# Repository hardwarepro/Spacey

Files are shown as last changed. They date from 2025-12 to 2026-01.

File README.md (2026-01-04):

# Spacey
A fully open-source space mouse! The current space mouse costs around $350 USD, so being able to build it for ~$75 USD is a HUGE reduction is cost for the same features (minus the screen). It has 10 hotkeyabled buttons, LEDs, a magnetometor for the space mouse part of it, and an amazingly designed CAD!

There are 2 main parts to this space mouse, the CAD + PCB for the keyboard, and the few parts for the space mouse part of it. Some photos of the CAD can be seen below, and can be viewed [here](https://cad.onshape.com/documents/f05fe75dfc18f89f5fcec945/w/6a3c1056693be4c34d9f2601/e/94b3cceea32ed90fe954c1a2). The PCB controls all the hotkeys, and the Xiao + magnetometor controls the actual space mouse ascpect. The space mouse part was partially taken from a tutorial though this was fully expanded to support hotkeys to act like the real and production-wise space mouse. Since the tutorial only convered those few main parts, all of the PCB + CAD shown below was all designed by myself.

## Photos

Screenshot 2025-12-13 at 5 34 07 PM

Screenshot 2025-12-13 at 5 34 35 PM



Screenshot 2025-12-12 at 12 20 18 AM

Screenshot 2025-12-12 at 12 20 33 AM

## BOM

## Full Total: $77.47 USD

## Parts for the Keyboard Part of it
| Item | Description | Quantity | Unit Price ($) | Total Price ($) | URL | Running Total ($ with Tax) |
|---|---|---|---|---|---|---|
| PCB | My PCB | x5 | $23.08 | $3.08 | [Link](https://jlcpcb.com) | $3.08 |
| Case | 3D Printed | 1 | Free | Free | N/A | $0 |
| XIAO-nRF52840 | MCU | 1 | $11.63 | $19.62 | [Link](https://ca.robotshop.com/fr/products/seeedstudioxiaonrf52840-fr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) | $19.62 |
| Buttons + LEDs + Screw Terminal | LCSC Parts for the PCB | 15 | $20 | $20 | [Link](https://lcsc.com) | $20 |
## Total with shipping + tax (USD): $42.7

## Parts for the space mouse part of it
| Item | Description | Quantity | Unit Price ($) | Total Price ($) | URL | Running Total ($ with Tax) |
|---|---|---|---|---|---|---|
| Adafruit QT Py RP2040 | MCU | 1 | $9.95 | $9.95 | [Link](https://www.adafruit.com/product/4900) | N/A |
| STEMMA QT / Qwiic JST SH 4-pin Cable - 50mm Long | JST Cable | 1 | $0.95 | $0.95 | [Link][https://www.adafruit.com/product/4210](https://www.aliexpress.com/item/1005007590874378.html) | N/A |
| Adafruit TLV493D | The main chip for the mouse- the magnetometer | 1 | $5.71 | $7.70 | [Link][https://www.aliexpress.com/item/1005007590874378.html](https://www.adafruit.com/product/4366) | N/A |
| Magnets | For the magnetometer | 1 | Free | Free | N/A | N/A |
## Total with shipping + tax (USD): $34.77

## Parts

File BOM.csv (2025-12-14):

Full Total | $77.47 USD
Parts for the Keyboard Part of it
Item | Description | Quantity | Unit Price ($) | Total Price ($) | URL | Running Total ($ with Tax)
PCB | My PCB | x5 | $23.08 | $3.08 | https://jlcpcb.com | $3.08
Case | 3D Printed | 1 | Free | Free | N/A | $0.00
XIAO-nRF52840 | MCU | 1 | $11.63 | $19.62 | https://ca.robotshop.com/fr/products/seeedstudioxiaonrf52840-fr | $19.62
Buttons + LEDs + Screw Terminal | LCSC Parts for the PCB | 15 | $20.00 | $20.00 | https://lcsc.com | $20.00
Total with shipping + tax (USD) | $42.70
Parts for the space mouse part of it
Item | Description | Quantity | Unit Price ($) | Total Price ($) | URL | Running Total ($ with Tax)
Adafruit QT Py RP2040 | MCU | 1 | $9.95 | $9.95 | https://www.adafruit.com/product/4900 | N/A
STEMMA QT / Qwiic JST SH 4-pin Cable - 50mm Long | JST Cable | 1 | $0.95 | $0.95 | https://www.adafruit.com/product/4210 | N/A
Adafruit TLV493D | The main chip for the mouse- the magnetometer | 1 | $5.95 | $5.95 | https://www.adafruit.com/product/4366 | N/A
Magnets | For the magnetometer | 1 | Free | Free | N/A | N/A
Total with shipping + tax (USD) | $34.77

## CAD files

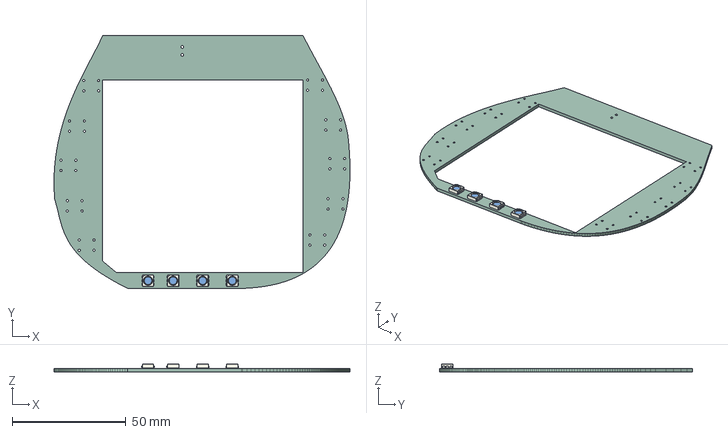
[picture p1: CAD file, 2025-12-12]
PCB/PCB.step
129.9 x 111.0 x 3.45 mm
LED_WS2812_PLCC6_5.0x5.0mm_P1.6mm x 4
spacey_PCB

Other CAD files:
PCB/.step

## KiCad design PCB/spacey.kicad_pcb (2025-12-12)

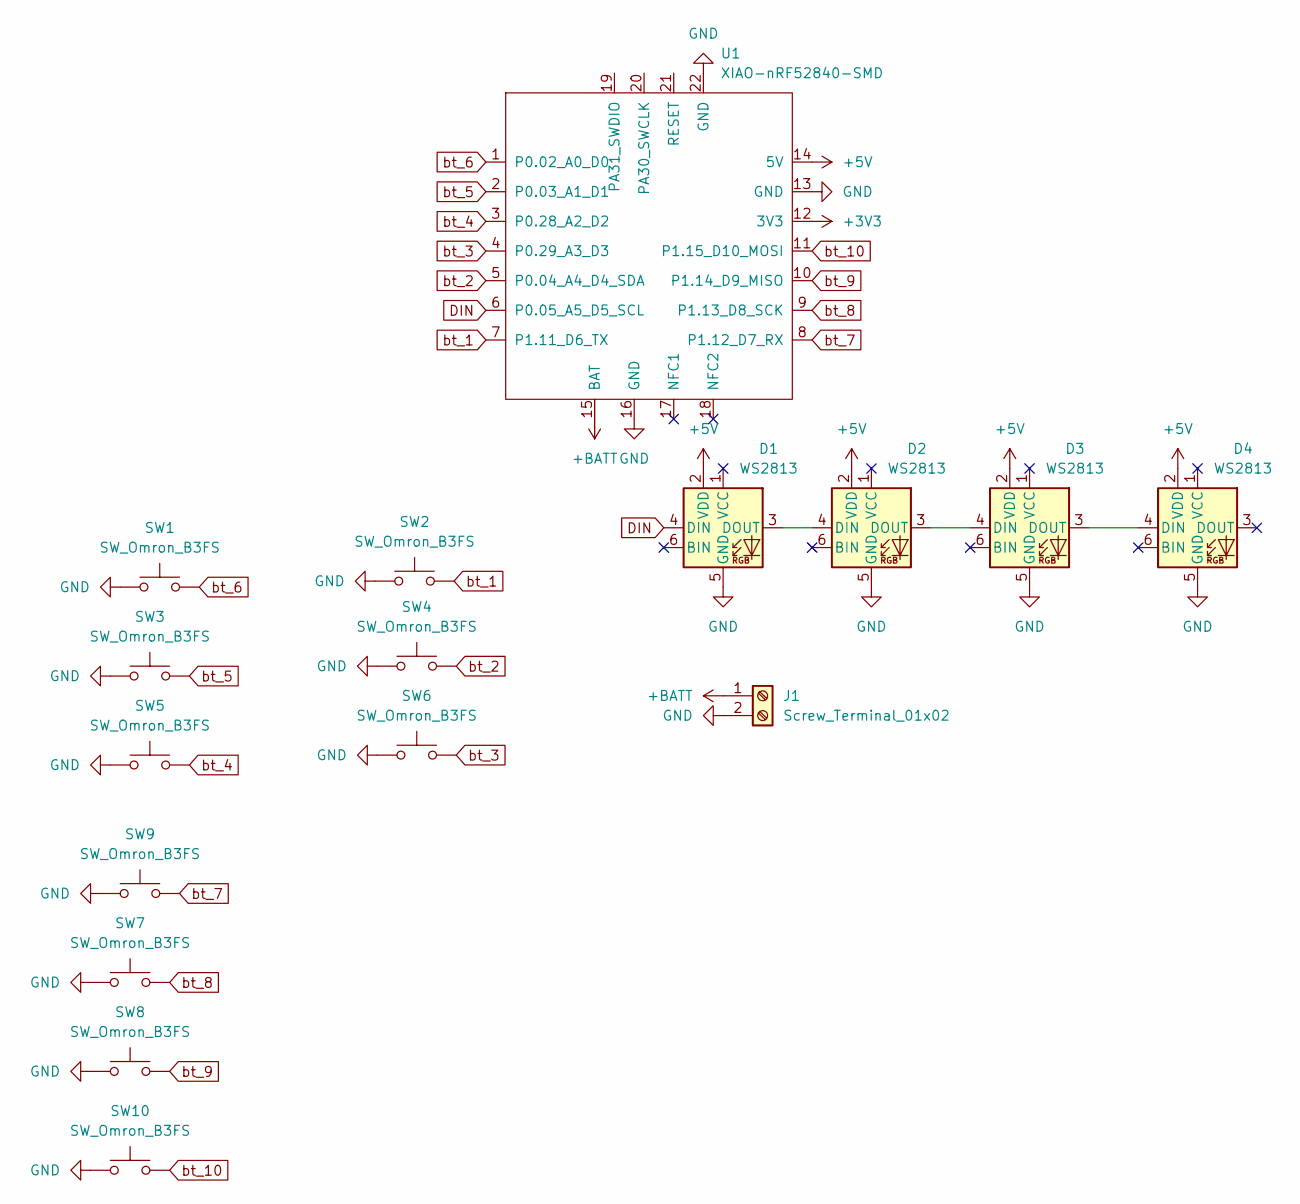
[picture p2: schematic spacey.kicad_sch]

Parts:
D1, D2, D3, D4: WS2813; LED_WS2812_PLCC6_5.0x5.0mm_P1.6mm
J1: Screw_Terminal_01x02; TerminalBlock_4Ucon_1x02_P3.50mm_Horizontal
SW1, SW2, SW3, SW4, SW5, SW6, SW7, SW8, SW9, SW10: SW_Omron_B3FS; SW_TH_Tactile_Omron_B3F-10xx
U1: XIAO-nRF52840-SMD

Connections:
+3V3: U1.12 (3V3)
+5V: D1.2 (VDD), D2.2 (VDD), D3.2 (VDD), D4.2 (VDD), U1.14 (5V)
+BATT: J1.1, U1.15 (BAT)
DIN: D1.4 (DIN), U1.6 (P0.05_A5_D5_SCL)
GND: D1.5 (GND), D2.5 (GND), D3.5 (GND), D4.5 (GND), J1.2, SW1.1, SW2.1, SW3.1, SW4.1, SW5.1, SW6.1, SW7.1, SW8.1, SW9.1, SW10.1, U1.13 (GND), U1.16 (GND), U1.22 (GND)
unnamed: D1.3 (DOUT), D2.4 (DIN)
unnamed: D2.3 (DOUT), D3.4 (DIN)
unnamed: D3.3 (DOUT), D4.4 (DIN)
bt_1: SW2.2, U1.7 (P1.11_D6_TX)
bt_2: SW4.2, U1.5 (P0.04_A4_D4_SDA)
bt_3: SW6.2, U1.4 (P0.29_A3_D3)
bt_4: SW5.2, U1.3 (P0.28_A2_D2)
bt_5: SW3.2, U1.2 (P0.03_A1_D1)
bt_6: SW1.2, U1.1 (P0.02_A0_D0)
bt_7: SW9.2, U1.8 (P1.12_D7_RX)
bt_8: SW7.2, U1.9 (P1.13_D8_SCK)
bt_9: SW8.2, U1.10 (P1.14_D9_MISO)
bt_10: SW10.2, U1.11 (P1.15_D10_MOSI)

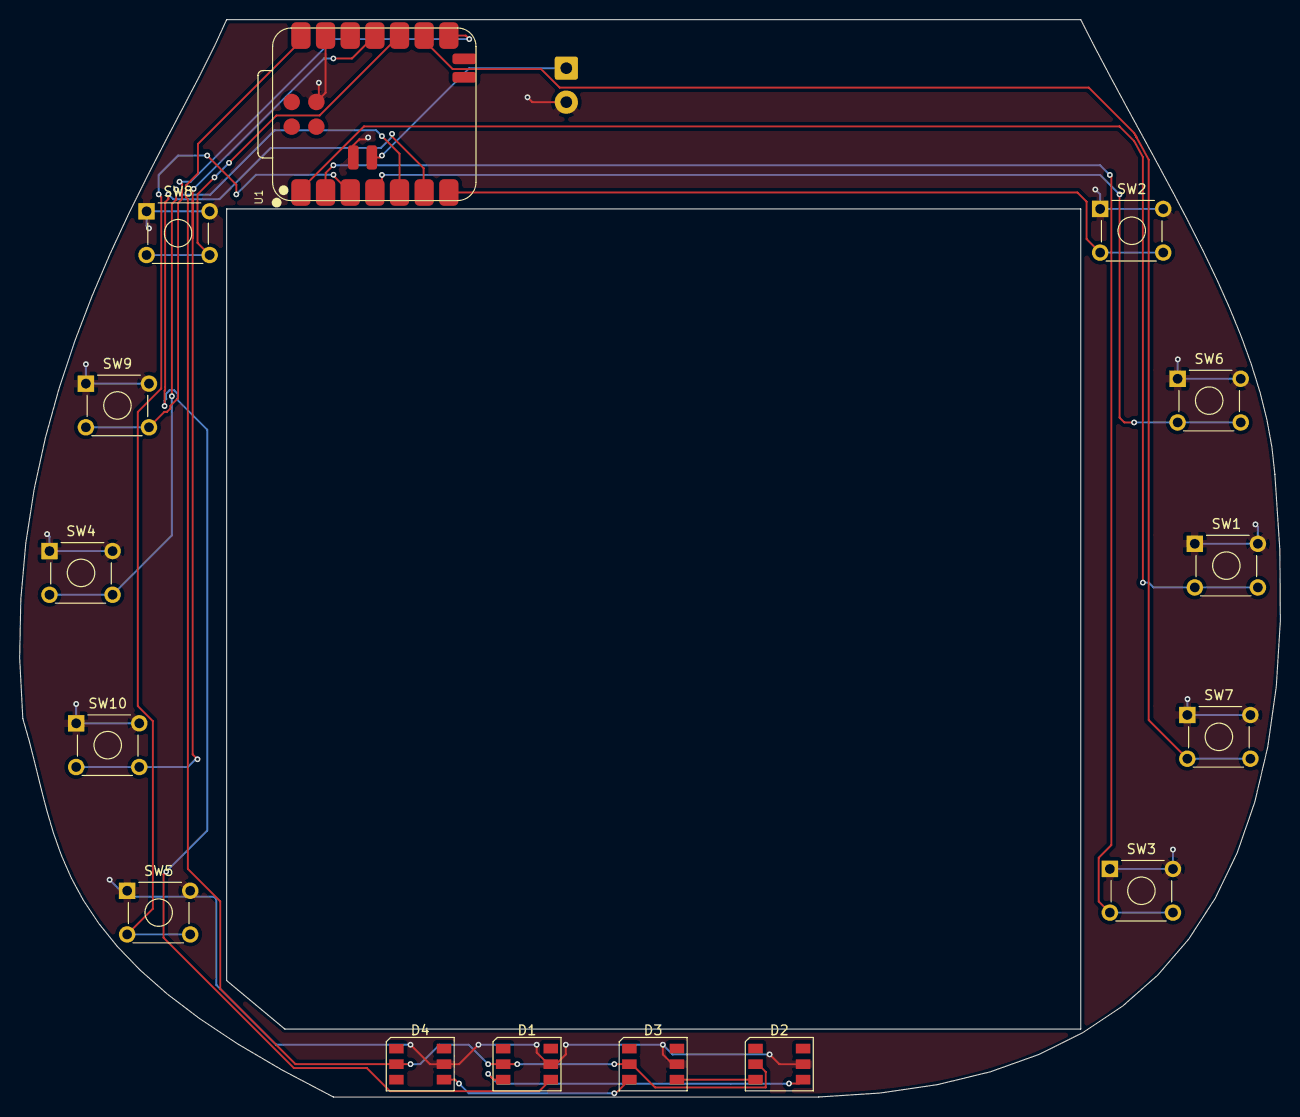
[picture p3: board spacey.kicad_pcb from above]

Board: 2 copper layers, 129.9 x 111.0 mm, 16 parts (1 on the bottom side), 17 nets.

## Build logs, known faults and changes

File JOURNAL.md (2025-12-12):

# Total time spent: 11 hours

## November 27th- 3 hours
### Schematic Making Time!
I was going through instrutables and I was looking for some cool projects related to CAD, as that is what I do a lot these days, and I stumbled across something called the Space Mouse. What this mouse does is it allows you to maintain greater control in your CAD space as there is usually a lot of buttons and stuff. This simplifies it to just a 3-axis wheel. After seeing this, I decided that I wanted to build it myself. The only problem I had was that if I only built the 3-axis wheel, I would mostly just be copying the tutorial and not actually making a PCB or anything. To combat this, I decided that I wanted to build the "more expensive space mouse" from scratch which also includes buttons for hotkeys, and a small screen for some quick actions. This will allow me to follow the tutorial on what parts to buy for the 3-axis part, while still allowing me to build the PCB for keyboard + screen aspect. On top of this, I hope to build all the CAD from scratch too and not using the tutorial's CAD for it. This is because I need it to be one piece for the keyboard + screen part too. So far, what I have done is build the schematic for the keys + a few LEDs to allow for some sick ambient lighting. I did a little bit of research and found that I wanted to use the bigger Xiao chip as it has more IO to allow me to add the right amount of keys + the LEDs + the screen. Even though this chip does have BL built it, it's not my goal to use it.


## December 11th- 4.5 hours
### Routed the PCB
I know I haven't made a journal for sometime mostly because I forgot and now that the deadline is coming, I kinda need to ship it lol. I've finished designing the PCB which including making the cool shape that will fit perfectly in my case and wrap around the space mouse. In the end, I decided to add 10 buttons and a few LED's to add lots of hotkeys for the space mouse's CAD. This was the model that was over $300USD, and I can make it perfectly for $200 less which is amazing! What took me the most amount of time was definitely trying to make this abomination of the shape that the PCB is in. KiCad doesn't make it too easy to do these shapes sadly. Once I got the shape done, I just figured out were I wanted the buttons based on how the space mouse online looks like which didn't take too long.

Also, while writing this journal, I looked over the PCB and found a few spacing DRC errors and fixed those while I was at it.



## December 11th- 4.5 hours
### Making the CAD!
Writing my next journal right after the last one since #1, I was given permission to do it, and #2, I kinda forgot to write one for like a week so I should probably write one. I've been practicing using onshape for the past few months now, so I'm starting to get the hang of it, and it's becoming a lot easier, and more fun for me to make stuff with it! I used to make a simple square case, and now I have just made a complicated case to replicate the space mouse design for the keyboard aspect of it. I forgot to write this in my last journal, but I ended up not including the screen, as if I was going too, I would need a fairly large one, and that would cost way too much money. So I decided to add more keys over a screen in the end. I know it may look quite complicated, but at it's core, it's not too complicated. It's just a sketch that I extruded up, and then another sketch going across to cut into it to create this shape. Hopefully this case will print well since it has a lot of curves, but with a little bit of sanding, it's going to look sick! If you want to see more on how I designed it, you can check it out here: https://cad.onshape.com/documents/f05fe75dfc18f89f5fcec945/w/6a3c1056693be4c34d9f2601/e/94b3cceea32ed90fe954c1a2!





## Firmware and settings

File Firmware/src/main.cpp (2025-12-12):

#include <Arduino.h>
#include <bluefruit.h>

const uint8_t BUTTON_PINS[] = {
  D0,
  D1,
  D2,
  D3,
  D4, 
  D5,
  D6,
  D7,
  D8,
  D9
};

const uint8_t NUM_BUTTONS = 10;

bool buttonStates[NUM_BUTTONS] = {false};
bool lastButtonStates[NUM_BUTTONS] = {false};
unsigned long lastDebounceTime[NUM_BUTTONS] = {0};
const unsigned long DEBOUNCE_DELAY = 50;

BLEDis bledis;
BLEHidAdafruit blehid;

BLEBas blebas;

const int LED_PIN = LED_BUILTIN;

void setup() {
  
  pinMode(LED_PIN, OUTPUT);
  digitalWrite(LED_PIN, LOW);
  
  for (uint8_t i = 0; i < NUM_BUTTONS; i++) {
    pinMode(BUTTON_PINS[i], INPUT_PULLUP);
    lastButtonStates[i] = digitalRead(BUTTON_PINS[i]);
  }
    
  Bluefruit.begin();
  Bluefruit.setTxPower(4);
  Bluefruit.setName("Spacey Mouse");
  
  bledis.setManufacturer("Spacey");
  bledis.setModel("Space Mouse!");
  bledis.begin();
  blehid.begin();
  
  blebas.begin();
  blebas.write(100);
  
  startAdv();
}

void startAdv(void) {
  Bluefruit.Advertising.addFlags(BLE_GAP_ADV_FLAGS_LE_ONLY_GENERAL_DISC_MODE);
  Bluefruit.Advertising.addTxPower();
  Bluefruit.Advertising.addAppearance(BLE_APPEARANCE_HID_KEYBOARD);
  
  Bluefruit.Advertising.addService(blehid);
  
  Bluefruit.Advertising.addName();
  
  Bluefruit.Advertising.restartOnDisconnect(true);
  Bluefruit.Advertising.setInterval(32, 244);
  Bluefruit.Advertising.setFastTimeout(30);
  Bluefruit.Advertising.start(0);
}

void sendOnshapeCommand(uint8_t buttonIndex) {
  if (!Bluefruit.connected()) {
    return;
  }
    
  switch(buttonIndex) {
    case 0:
      blehid.keyboardReport(0, HID_KEY_R);
      delay(10);
      blehid.keyRelease();
      break;
      
    case 1:
      blehid.keyboardReport(KEYBOARD_MODIFIER_LEFTSHIFT, HID_KEY_R);
      delay(10);
      blehid.keyRelease();
      break;
      
    case 2: 
      blehid.keyboardReport(0, HID_KEY_Z);
      delay(10);
      blehid.keyRelease();
      break;
      
    case 3:
      blehid.keyboardReport(0, HID_KEY_F);
      delay(10);
      blehid.keyRelease();
      break;
      
    case 4:
      blehid.keyboardReport(0, HID_KEY_SPACE);
      delay(10);
      blehid.keyRelease();
      delay(50);
      blehid.keyboardReport(0, HID_KEY_2);
      delay(10);
      blehid.keyRelease();
      break;
      
    case 5:
      blehid.keyboardReport(0, HID_KEY_SPACE);
      delay(10);
      blehid.keyRelease();
      delay(50);
      blehid.keyboardReport(0, HID_KEY_1);
      delay(10);
      blehid.keyRelease();
      break;
      
    case 6:
      blehid.keyboardReport(0, HID_KEY_SPACE);
      delay(10);
      blehid.keyRelease();
      delay(50);
      blehid.keyboardReport(0, HID_KEY_3);
      delay(10);
      blehid.keyRelease();
      break;
      
    case 7: 
      blehid.keyboardReport(0, HID_KEY_SPACE);
      delay(10);
      blehid.keyRelease();
      delay(50);
      blehid.keyboardReport(0, HID_KEY_7);
      delay(10);
      blehid.keyRelease();
      break;
      
    case 8:
      blehid.keyboardReport(0, HID_KEY_V);
      delay(10);
      blehid.keyRelease();
      break;
      
    case 9:
      blehid.keyboardReport(KEYBOARD_MODIFIER_LEFTCTRL | KEYBOARD_MODIFIER_LEFTSHIFT, HID_KEY_R);
      delay(10);
      blehid.keyRelease();
      break;
  }
}

void loop() {
  static bool ledState = false;
  static unsigned long lastBlink = 0;
  
  if (Bluefruit.connected()) {
    digitalWrite(LED_PIN, HIGH);
  } else {
    if (millis() - lastBlink > 500) {
      ledState = !ledState;
      digitalWrite(LED_PIN, ledState);
      lastBlink = millis();
    }
  }
  
  for (uint8_t i = 0; i < NUM_BUTTONS; i++) {
    bool reading = !digitalRead(BUTTON_PINS[i]);
    
    if (reading != lastButtonStates[i]) {
      lastDebounceTime[i] = millis();
    }
    
    if ((millis() - lastDebounceTime[i]) > DEBOUNCE_DELAY) {
      if (reading != buttonStates[i]) {
        buttonStates[i] = reading;
        
        if (buttonStates[i]) {
          sendOnshapeCommand(i);
        }
      }
    }
    lastButtonStates[i] = reading;
  }
  delay(1);
}

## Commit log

2025-12-04 Finished PCB
    [spacey.kicad_pcb, spacey.kicad_sch, spacey.stl]
2025-12-12 Fixed DRC errors
    [spacey.kicad_pcb]
2025-12-12 Added CAD and PCB folders
    [.step, PCB.step, spacey.kicad_pcb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]
2025-12-12 Made the BOM.md
2025-12-12 should be good now!
    [spacey.step, spacey.stl]
2025-12-12 added the 3d models + made a new step file
    [spacey.kicad_pcb]
2025-12-14 Changed it to a .csv
    [BOM.csv]
